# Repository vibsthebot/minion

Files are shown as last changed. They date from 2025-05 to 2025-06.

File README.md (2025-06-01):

# Minion - The Swiss Army Knife of Electronics

3D Model

I'm a mac user, and i love my apple wired headphones.
mN phone doesn't have headphone jack and my computer doesn't have micro sd or usb a.
What if i made a dongle to rule all dongles, but added a potentiometer for step tracking and display + buttons to play games? And thats how I made Minion.

## Features

- USB hub with usb c input, usb a and microsd output
- TRRS jack for headphones
- Bourns Rotary Encoder
- Built-in display (SSD1351)
- Tactile buttons for user input
- Robust case design with custom rotary encoder cover and button extensions

## [Onshape](https://cad.onshape.com/documents/3528835cd7c24f4fa682b200/w/cef528dd0bdfad9cc29e4192/e/ba726118fc6deb21c1d0aa06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)

## Images

### Schematic
Schematic

### PCB Layout
PCB

### 3D Model of PCB

3D Model

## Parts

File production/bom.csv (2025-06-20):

Designator | Footprint | Quantity | Value | LCSC Part #
BT1 | JST_PH_S2B-PH-K_1x02_P2.00mm_Horizontal | 1 | Battery | C265016
C1, C22, C27, C28 | 0805 | 4 | 4.7uF | C1779
C10, C11, C2, C23, C4, C5, C7 | 0805 | 7 | 10uF | C15850
C12, C13, C14, C15, C16, C17 | 0805 | 6 | 1uF | C28323
C18, C20, C21, C24, C26, C29, C3, C30, C31, C6, C8, C9 | 0805 | 12 | 0.1uF | C28233
C32, C33 | 0402 | 2 | 18pF | C1549
D1 | 0805 | 1 | PWRLED | C84256
D8 | 0805 | 1 | Orange | C434437
D9 | D_SOD-123 | 1 | MBR0540 | C77337
J1 | USB_C_Receptacle_HCTL_HC-TYPE-C-16P-01A | 1 | USB_C_Receptacle_USB2.0_16P | C134092
J2 | USB_A_Molex_67643_Horizontal | 1 | USB_A | C464564
J3 | CONN12_47309-2651_MOL | 1 | 473092651 | C587826
J4 | HRO_PJ-320D-A | 1 | PJ-320D-A | C95562
J5 | SSD_1351 | 1 | Conn_01x07_Socket | C124418
Q1 | SOT-23 | 1 | AO3401A | C306862
R1, R10, R2 | 0805 | 3 | 1k | C17513
R11 | 0805 | 1 | 2k | C17604
R12 | 0805 | 1 | 0.47k | C17710
R13, R14, R8, R9 | 0805 | 4 | 4k7 | C17673
R15, R16, R20, R5, R6, R7 | 0805 | 6 | 10k | C17414
R17, R18, R21 | 0805 | 3 | 100k | C149504
R19 | 0805 | 1 | 1M | C17514
R22 | 0805 | 1 | 12k | C17444
R3, R4 | 0805 | 2 | 5k1 | C27834
SW1, SW2, SW3 | SW_Push_1P1T_NO_6x6mm_H9.5mm | 3 | SW_Push | C455110
SW4 | RotaryEncoder_Bourns_Vertical_PEC12R-3x17F-Nxxxx | 1 | RotaryEncoder | C18164805
SW5, SW6 | SW_Push_1P1T_NO_CK_KMR2 | 2 | SW_Push | C221676
U1 | ESP32-S3-WROOM-1 | 1 | ESP32-S3-WROOM-1 | C2913204
U2, U3 | SOT-23-5 | 2 | AP2112K-3.3 | C51118
U4 | LGA-14_3x5mm_P0.8mm_LayoutBorder1x6y | 1 | ADXL343 | C579454
U6 | DFN-8-1EP_3x2mm_P0.5mm_EP1.7x1.4mm | 1 | MCP73831-2-MC | C150772
U7 | TSSOP-20_4.4x6.5mm_P0.65mm | 1 | PCM5102A | C1520792
U8 | QFN48_7X7MC_MCH | 1 | USB2641I-HZH-02 | C633597
Y3 | Crystal_SMD_5032-2Pin_5.0x3.2mm | 1 | 24MHz | C122520

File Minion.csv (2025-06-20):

Reference | Qty | Value | DigiKey | LCSC | DNP | Exclude from BOM | Exclude from Board | Footprint | Datasheet | MFR_NAME
BT1 | 1 | Battery |  | C265016 |  |  |  | Connector_JST:JST_PH_S2B-PH-K_1x02_P2.00mm_Horizontal | ~
C1,C19,C22 | 3 | 4.7uF |  | C40894 |  |  |  | Capacitor_SMD:C_0805_2012Metric | ~
C2,C12,C13,C14,C15,C16,C17 | 7 | 1uF |  | C215803 |  |  |  | Capacitor_SMD:C_0805_2012Metric | ~
C3,C6,C8,C9,C10,C18,C20,C21,C24 | 9 | 0.1uF |  | C476766 |  |  |  | Capacitor_SMD:C_0805_2012Metric | ~
C4,C5,C7,C11,C23 | 5 | 10uF |  | C40894 |  |  |  | Capacitor_SMD:C_0805_2012Metric | ~
D1 | 1 | PWRLED |  | C84256 |  |  |  | LED_SMD:LED_0805_2012Metric | ~
D2,D3,D4,D5 | 4 | WS2812B |  | C114586 |  |  |  | LED_SMD:LED_WS2812B_PLCC4_5.0x5.0mm_P3.2mm | https://cdn-shop.adafruit.com/datasheets/WS2812B.pdf
D6 | 1 | S-LMBR340FT1G |  | C2972823 |  |  |  | Diode_SMD:D_SOD-123F | ~
D8 | 1 | Orange |  | C434437 |  |  |  | LED_SMD:LED_0805_2012Metric | ~
D9 | 1 | MBR0540 |  | C77337 |  |  |  | Diode_SMD:D_SOD-123 | http://www.mccsemi.com/up_pdf/MBR0520~MBR0580(SOD123).pdf
DISPLAY_SSD1351 | 1 | Conn_01x07_Socket |  | C124418 |  |  |  | Connector_PinHeader_2.54mm:SSD_1351 | ~
H1,H2 | 2 | MountingHole |  |  |  | Excluded from BOM |  | MountingHole:MountingHole_2.2mm_M2 | ~
J1 | 1 | USB_C_Receptacle_USB2.0_16P | 900-2171790001CT-ND |  |  |  |  | Connector_USB:USB_C_Receptacle_HCTL_HC-TYPE-C-16P-01A | https://www.usb.org/sites/default/files/documents/usb_type-c.zip
J2 | 1 | USB_A |  | C464564 |  |  |  | Connector_USB:USB_A_Molex_67643_Horizontal | ~
J3 | 1 | 473092651 | WM6700CT-ND |  |  |  |  | 473092651:CONN12_47309-2651_MOL |  | Molex Connector Corporation
J4 | 1 | PJ-320D-A |  | C95562 |  |  |  | PJ-320D-A:HRO_PJ-320D-A
Q1 | 1 | AO3401A |  | C306862 |  |  |  | Package_TO_SOT_SMD:SOT-23 | http://www.aosmd.com/pdfs/datasheet/AO3401A.pdf
R1,R2,R10 | 3 | 1k |  | C95781 |  |  |  | Resistor_SMD:R_0805_2012Metric | ~
R3,R4 | 2 | 5.1k |  | C27834 |  |  |  | Resistor_SMD:R_0805_2012Metric | ~
R5,R6 | 2 | 10k |  | C2930231 |  |  |  | Resistor_SMD:R_0805_2012Metric | ~
R7 | 1 | 2.7k |  | C2907305 |  |  |  | Resistor_SMD:R_0805_2012Metric | ~
R8,R9,R13,R14 | 4 | 4.7k |  | C60816 |  |  |  | Resistor_SMD:R_0805_2012Metric | ~
R11 | 1 | 2k |  | C60816 |  |  |  | Resistor_SMD:R_0805_2012Metric | ~
R12 | 1 | 0.47k |  | C60816 |  |  |  | Resistor_SMD:R_0805_2012Metric | ~
SW1,SW2,SW3 | 3 | SW_Push |  | C455110 |  |  |  | Button_Switch_SMD:SW_Push_1P1T_NO_6x6mm_H9.5mm | ~
SW4 | 1 | RotaryEncoder |  | C18164805 |  |  |  | Rotary_Encoder:RotaryEncoder_Bourns_Vertical_PEC12R-3x17F-Nxxxx | ~
SW5,SW6 | 2 | SW_Push |  | C221676 |  |  |  | Button_Switch_SMD:SW_Push_1P1T_NO_CK_KMR2 | ~
U1 | 1 | ESP32-S3-WROOM-1 |  | C2913204 |  |  |  | RF_Module:ESP32-S3-WROOM-1 | https://www.espressif.com/sites/default/files/documentation/esp32-s3-wroom-1_wroom-1u_datasheet_en.pdf
U2 | 1 | AMS1117-3.3 | 4518-AMS1117-3.3CT-ND |  |  |  |  | Package_TO_SOT_SMD:SOT-223-3_TabPin2 | http://www.advanced-monolithic.com/pdf/ds1117.pdf
U3 | 1 | FE1.1s |  | C9359 |  |  |  | Package_SO:SSOP-28_3.9x9.9mm_P0.635mm | https://cdn-shop.adafruit.com/product-files/2991/FE1.1s+Data+Sheet+(Rev.+1.0).pdf
U4 | 1 | ADXL343 | 505-ADXL343BCCZ-ND |  |  |  |  | Package_LGA:LGA-14_3x5mm_P0.8mm_LayoutBorder1x6y | https://www.analog.com/media/en/technical-documentation/data-sheets/ADXL343.pdf
U5 | 1 | CH376T |  | C21282 |  |  |  | Package_SO:SSOP-20_5.3x7.2mm_P0.65mm | https://www.mpja.com/download/ch376ds1.pdf
U6 | 1 | MCP73831-2-MC |  | C150772 |  |  |  | Package_DFN_QFN:DFN-8-1EP_3x2mm_P0.5mm_EP1.7x1.4mm | http://ww1.microchip.com/downloads/en/DeviceDoc/20001984g.pdf
U7 | 1 | PCM5102A | 296-36707-1-ND |  |  |  |  | Package_SO:TSSOP-20_4.4x6.5mm_P0.65mm | https://www.ti.com/lit/ds/symlink/pcm5102a.pdf
Y1,Y2 | 2 | 12MHz |  | C3035202 |  |  |  | Crystal:Crystal_SMD_5032-2Pin_5.0x3.2mm | ~

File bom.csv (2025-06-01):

Qty | Item | LCSC/DigiKey Min Quantity | Individual Price | What the price should be | What the price really is | Price for 2 boards | LCSC Part Number | DigiKey Part Number | Link/Notes
1 | Battery | 10 | 0.0621 | 0.0621 | 0.621 | 0.62 | C265016
5 | 10uF | 50 | 0.012 | 0.06 | 0.6 | 0.6 | C40894
7 | 1uF | 25 | 0.0034 | 0.0238 | 0.085 | 0.09 | C215803
5 | 0.1uF | 20 | 0.0097 | 0.0485 | 0.194 | 0.19 | C476766
1 | PWRLED | 50 | 0.013 | 0.013 | 0.65 | 0.65 | C84256
4 | WS2812B | 5 | 0.0835 | 0.334 | 0.4175 | 0.84 | C114586
1 | S-LMBR340FT1G | 10 | 0.0249 | 0.0249 | 0.249 | 0.25 | C2972823
1 | Orange | 50 | 0.0088 | 0.0088 | 0.44 | 0.44 | C434437
1 | MBR0540 | 20 | 0.0313 | 0.0313 | 0.626 | 0.63 | C77337
1 | Conn_01x07_Socket | 5 | 0.1469 | 0.1469 | 0.7345 | 0.73 | C124418
1 | USB_C_Receptacle_USB2.0_16P | 1 | 0.83 | 0.83 | 0.83 | 1.66 |  | 900-2171790001CT-ND
1 | USB_A | 1 | 0.5764 | 0.5764 | 0.5764 | 1.15
1 | 473092651 | 1 | 1.94 | 1.94 | 1.94 | 3.88 | C464564 | WM6700CT-ND
1 | PJ-320D-A | 5 | 0.0972 | 0.0972 | 0.486 | 0.49
1 | AO3401A | 20 | 0.0521 | 0.0521 | 1.042 | 1.04 | C95562
3 | 1k | 100 | 0.0019 | 0.0057 | 0.19 | 0.19 | C306862
2 | 5.1k | 100 | 0.0019 | 0.0038 | 0.19 | 0.19 | C95781
2 | 10k | 100 | 0.0012 | 0.0024 | 0.12 | 0.12 | C27834
1 | 2.7k | 100 | 0.0013 | 0.0013 | 0.13 | 0.13 | C2930231
6 | 4.7k | 100 | 0.0022 | 0.0132 | 0.22 | 0.22 | C2907305
3 | SW_Push | 10 | 0.0427 | 0.1281 | 0.427 | 0.43 | C60816
1 | RotaryEncoder | 1 | 2.3596 | 2.3596 | 2.3596 | 4.72 | C455110
2 | SW_Push | 1 | 0.4706 | 0.9412 | 0.9412 | 1.88 | C18164805
1 | ESP32-S3-WROOM-1 | 1 | 5.8792 | 5.8792 | 5.8792 | 11.76 | C221676
1 | AMS1117-3.3 | 1 | 0.68 | 0.68 | 0.68 | 1.36 | C2913204 | 4518-AMS1117-3.3CT-ND
1 | FE1.1s | 1 | 0.6214 | 0.6214 | 0.6214 | 1.24
1 | ADXL343 | 1 | 3.35 | 3.35 | 3.35 | 6.7 | C9359 | 505-ADXL343BCCZ-ND
1 | CH376T | 1 | 3.6696 | 3.6696 | 3.6696 | 7.34
1 | MCP73831-2-MC | 1 | 1.2194 | 1.2194 | 1.2194 | 2.44 | C21282
1 | PCM5102A | 1 | 4.43 | 4.43 | 4.43 | 8.86 | C150772 | 296-36707-1-ND
2 | 12MHz | 5 | 0.1676 | 0.3352 | 0.838 | 0.84
1 | SSD1351 | 1 | 19.55 | 19.55 | 19.55 | 19.55 | C3035202
1 | Stencils + PCB | 1 | 16 | 16 | 16 | 16 |  |  | https://www.aliexpress.us/item/2255799949791867.html
1 | JLCCNC Machined case | 1 | 61.87 | 61.87 | 61.87 | 61.87 |  |  | optional, may get manufactured in house
1 | DigiKey Shipping | 1 | 8 | 8 | 8 | 8
1 | LCSC + JLC shipping | 1 | 20 | 20 | 20 | 20
 |  |  | 152.2099 | 153.3091 | 160.1768 | 187.1

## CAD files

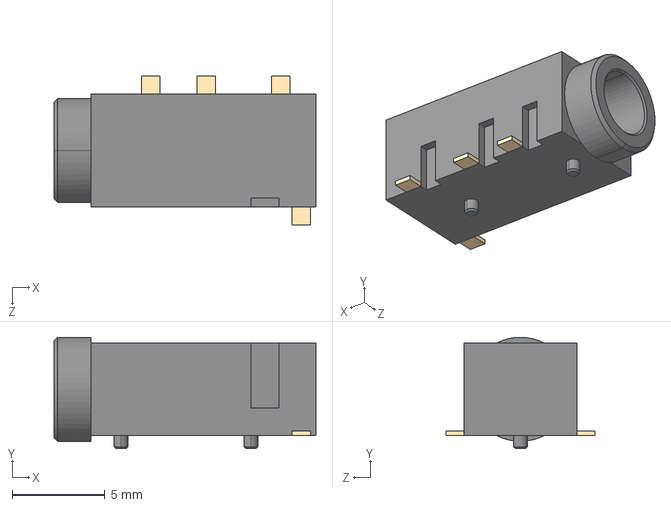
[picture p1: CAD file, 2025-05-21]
3d models/PJ-320D-A--3DModel-STEP-56544.STEP
14.1 x 6.00 x 8.00 mm

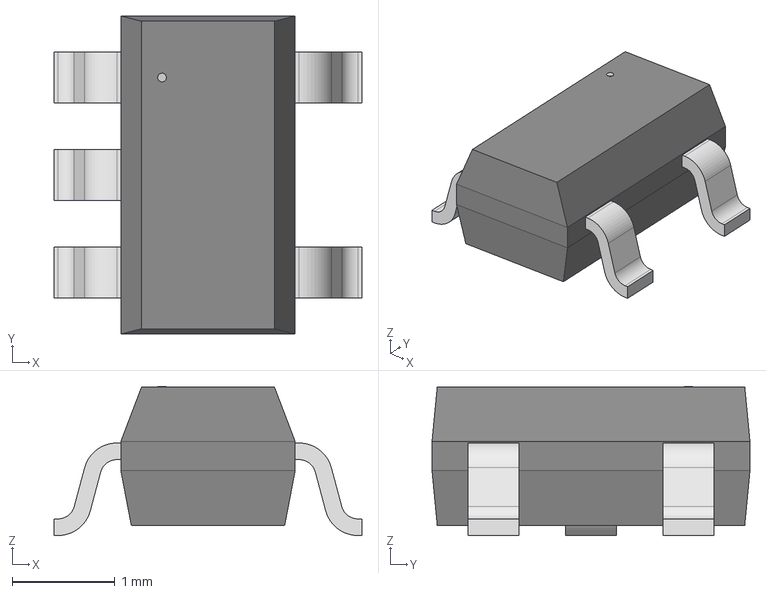
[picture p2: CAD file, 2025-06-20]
74AHCT1G125W5_7/SOT25_DIO.step
3.00 x 3.10 x 1.45 mm

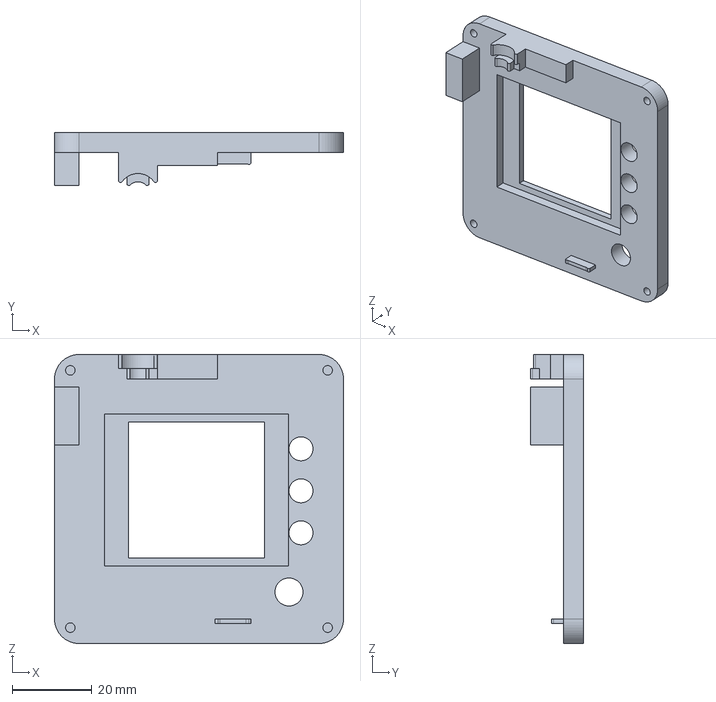
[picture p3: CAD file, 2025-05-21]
CAD/top_shell.step
72.3 x 13.3 x 72.3 mm

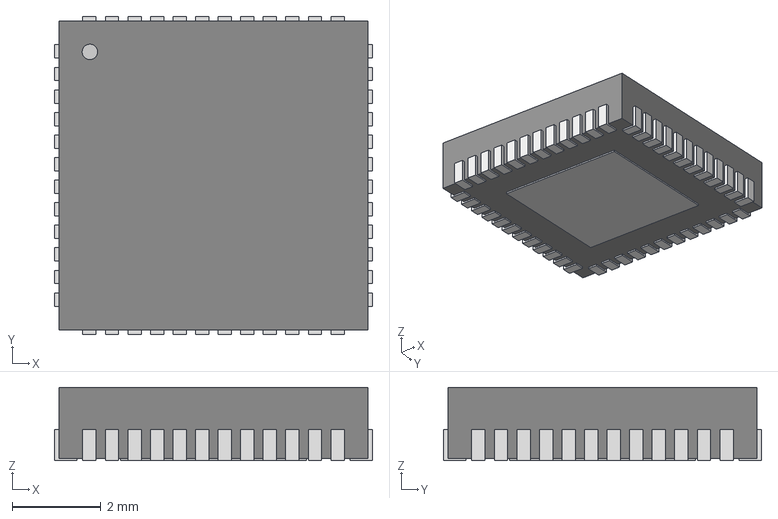
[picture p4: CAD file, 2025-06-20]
USB2641I_HZH_02/QFN48_7X7MC_MCH.step
7.16 x 7.16 x 1.65 mm

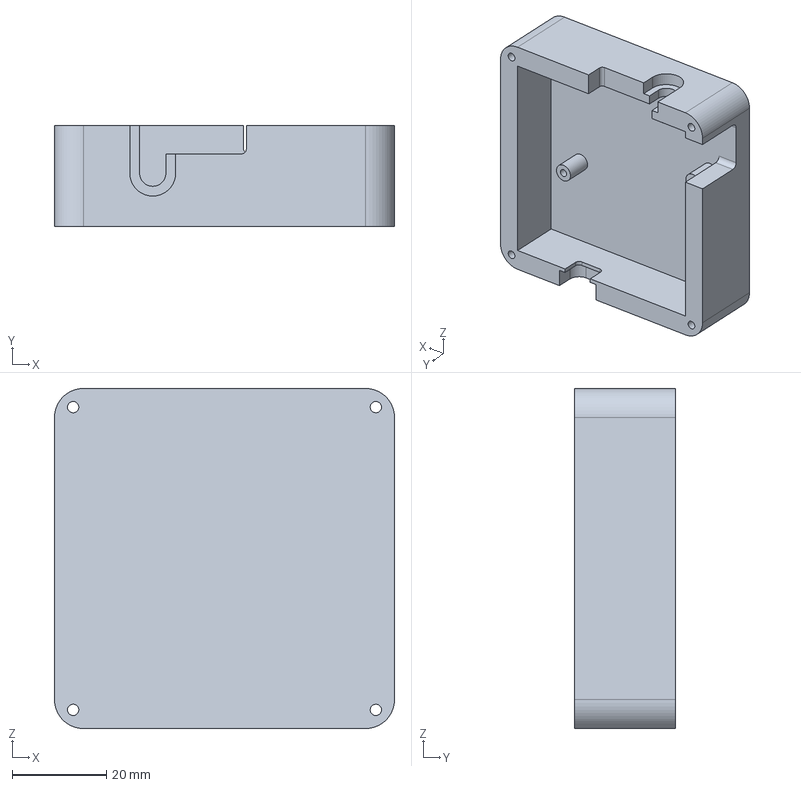
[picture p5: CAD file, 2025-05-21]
CAD/bottom_shell.step
72.3 x 21.5 x 72.3 mm

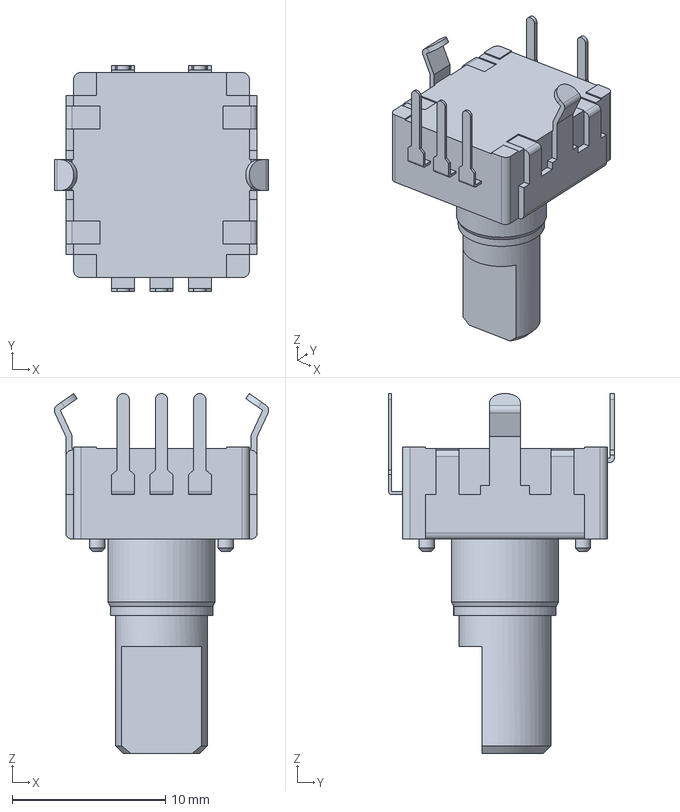
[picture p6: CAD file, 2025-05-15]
3d models/pec12r-4020f-n0024.step
14.0 x 14.7 x 23.5 mm

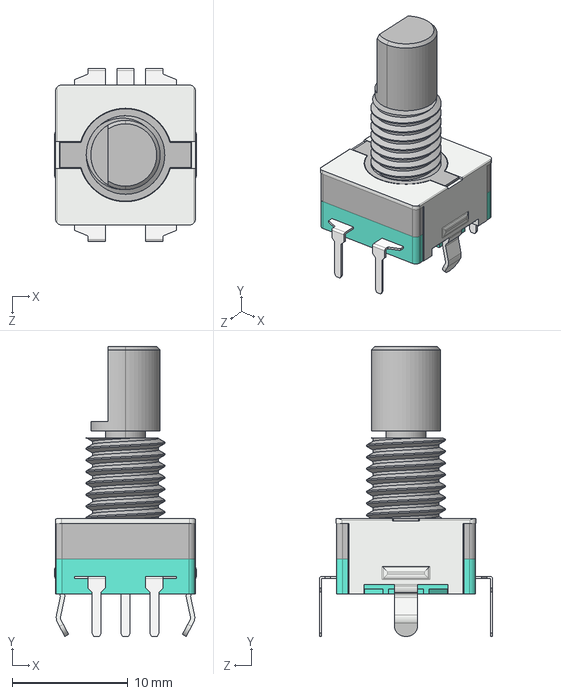
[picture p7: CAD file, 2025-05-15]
3d models/ec11.STEP
12.3 x 25.1 x 15.0 mm

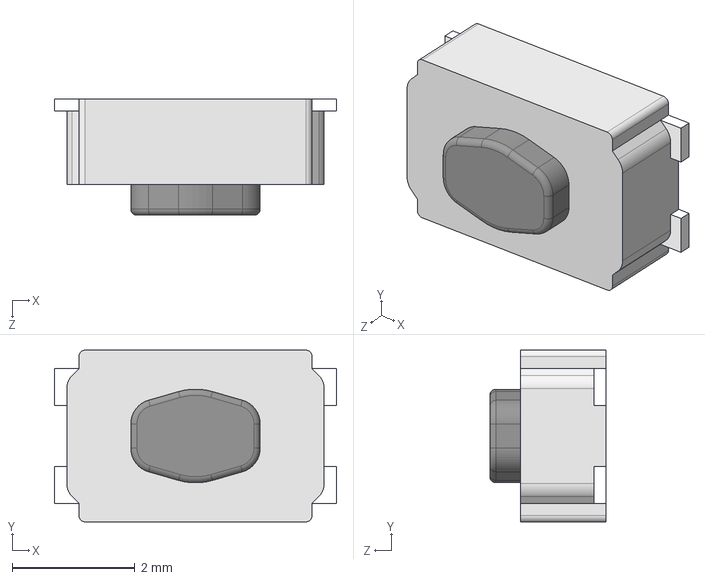
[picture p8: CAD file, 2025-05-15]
3d models/CK-KMR-2.STEP
4.60 x 2.80 x 1.90 mm

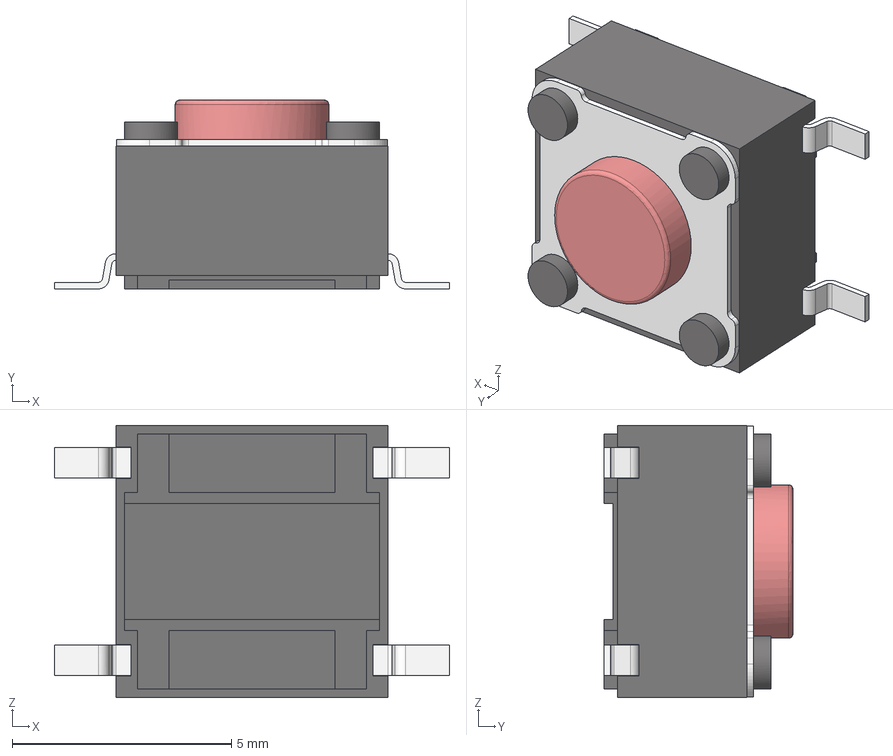
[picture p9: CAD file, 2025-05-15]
3d models/Tact Switch SMD 6x6mm.step
9.00 x 4.30 x 6.20 mm

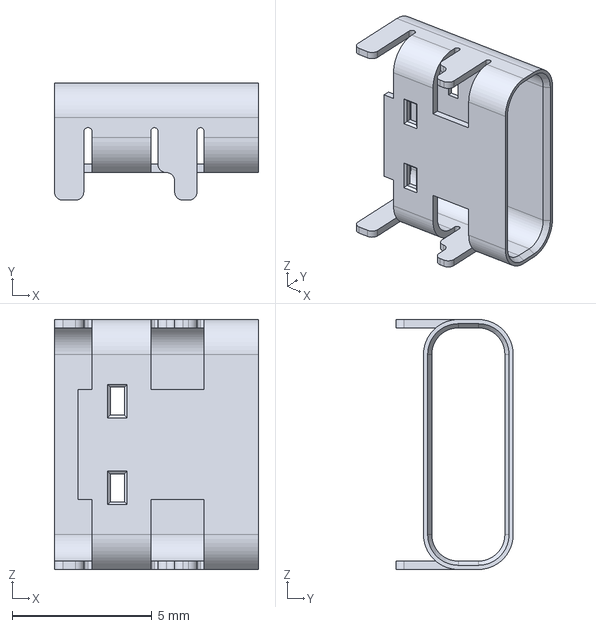
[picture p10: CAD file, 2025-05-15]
3d models/usb-c horizontal surface mount - usbc.step
7.30 x 4.20 x 8.94 mm

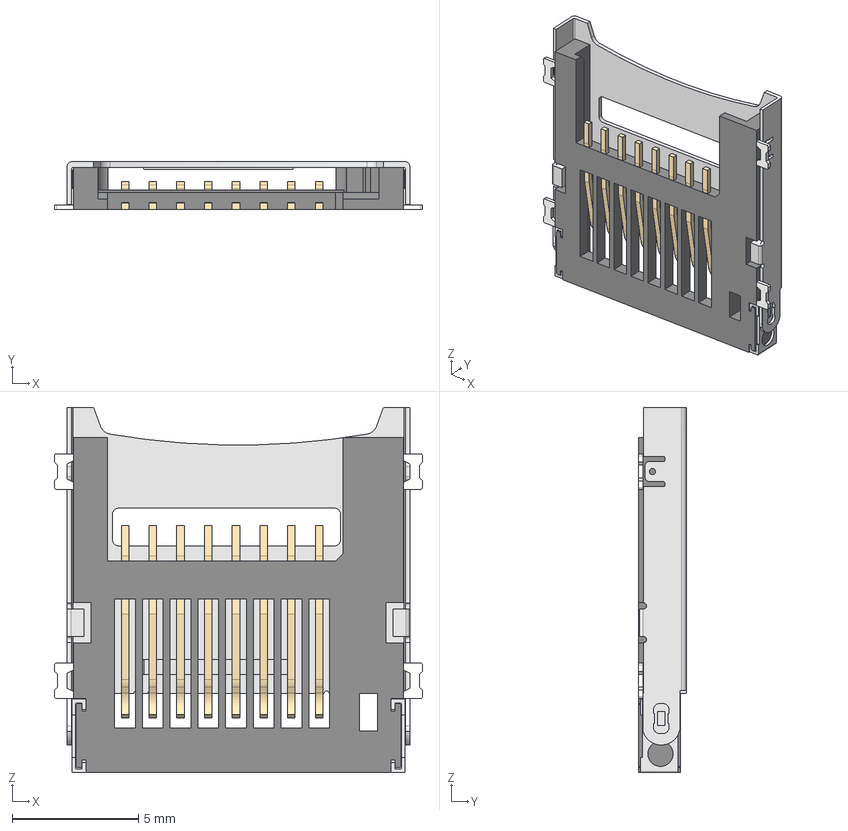
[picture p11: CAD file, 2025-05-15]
3d models/molex-47219-2001-1.snapshot.1/472192001 v1.step
14.6 x 1.90 x 14.5 mm
Pins
Mounting
Cover
Hinge

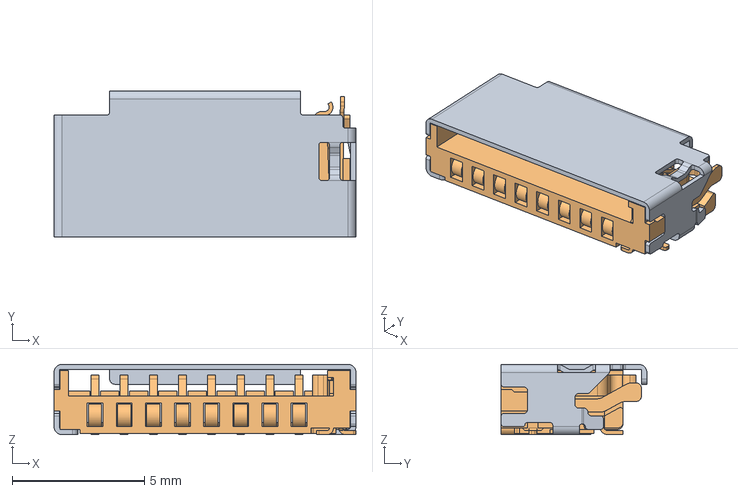
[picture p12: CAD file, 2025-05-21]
3d models/473092651.stp
11.4 x 5.50 x 2.65 mm

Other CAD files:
3d models/molex-47219-2001-1.snapshot.1/472192001 v1.f3d

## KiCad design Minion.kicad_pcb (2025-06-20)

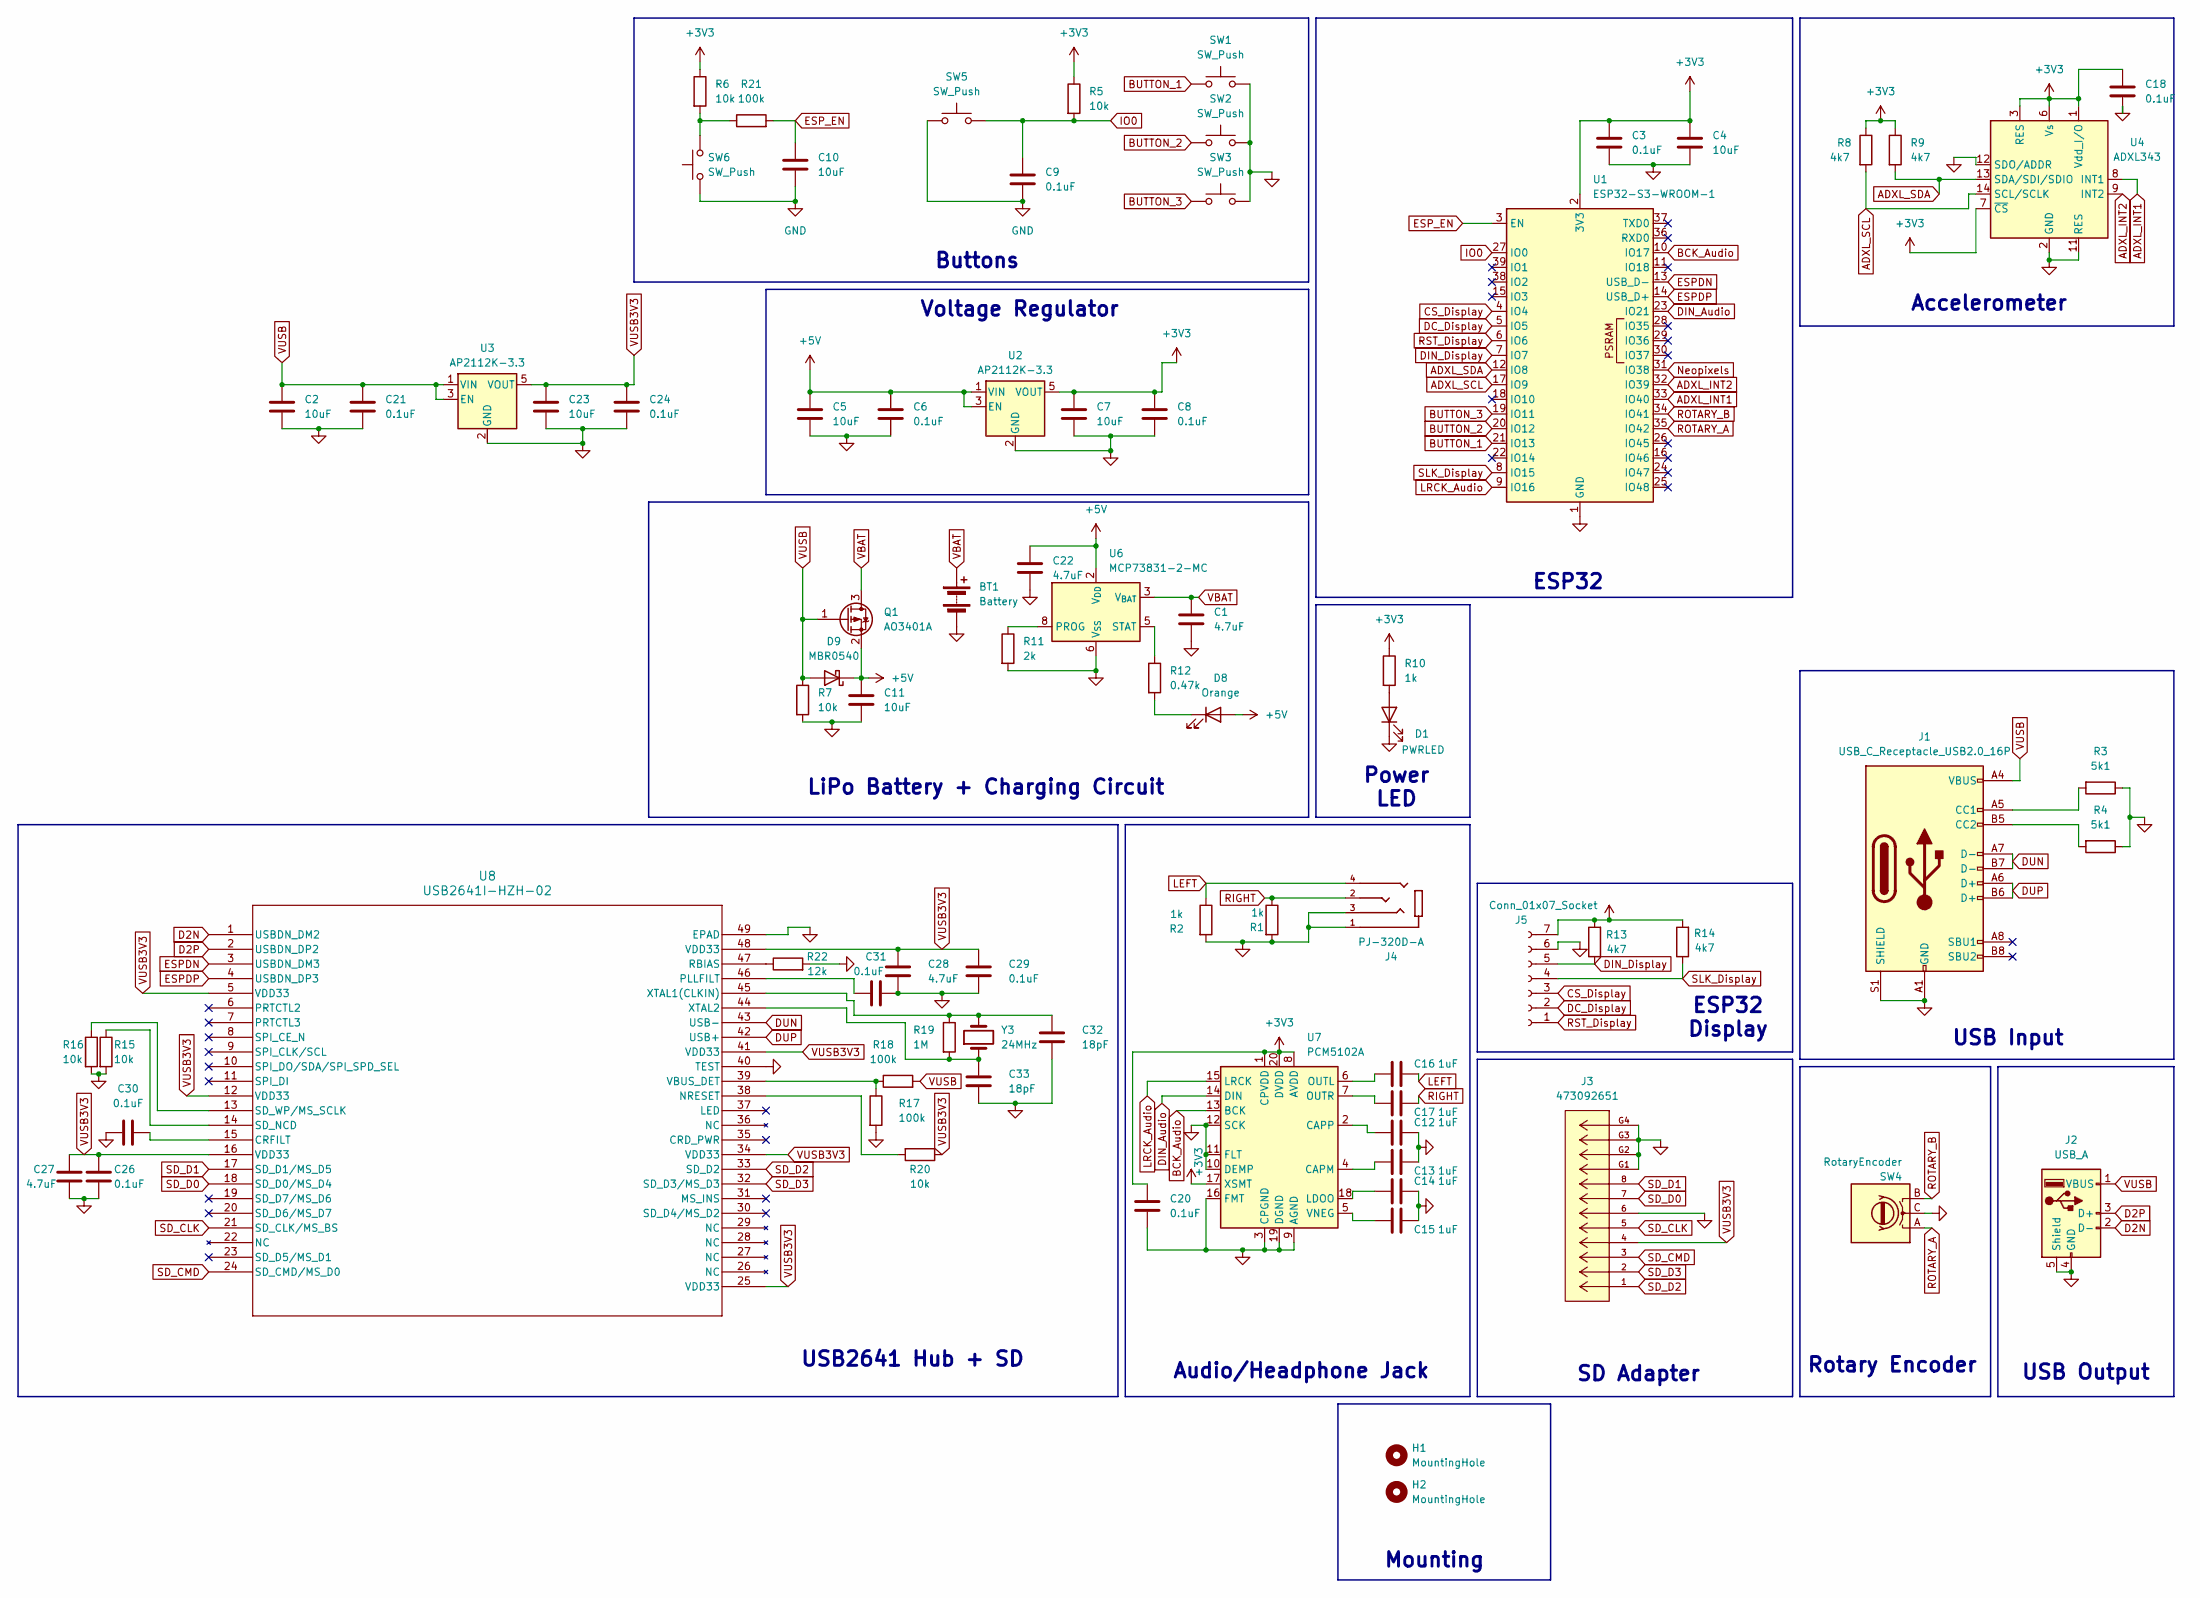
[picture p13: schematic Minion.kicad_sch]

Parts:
BT1: Battery; JST_PH_S2B-PH-K_1x02_P2.00mm_Horizontal; LCSC C265016
C1, C22, C27, C28: 4.7uF; C_0805_2012Metric; LCSC C1779
C2, C4, C5, C7, C10, C11, C23: 10uF; C_0805_2012Metric; LCSC C15850
C3, C6, C8, C9, C18, C20, C21, C24, C26, C29, C30, C31: 0.1uF; C_0805_2012Metric; LCSC C28233
C12, C13, C14, C15, C16, C17: 1uF; C_0805_2012Metric; LCSC C28323
C32, C33: 18pF; C_0402_1005Metric; LCSC C1549
D1: PWRLED; LED_0805_2012Metric; LCSC C84256
D8: Orange; LED_0805_2012Metric; LCSC C434437
D9: MBR0540; D_SOD-123; LCSC C77337
H1, H2: MountingHole; MountingHole_2.2mm_M2
J1: USB_C_Receptacle_USB2.0_16P; USB_C_Receptacle_HCTL_HC-TYPE-C-16P-01A; DigiKey 900-2171790001CT-ND
J2: USB_A; USB_A_Molex_67643_Horizontal; LCSC C464564
J3: 473092651; CONN12_47309-2651_MOL; MANUFACTURER_PART_NUMBER 473092651; DigiKey WM6700CT-ND
J4: PJ-320D-A; HRO_PJ-320D-A; PARTREV B; LCSC C95562
J5: Conn_01x07_Socket; SSD_1351; LCSC C124418
Q1: AO3401A; SOT-23; LCSC C306862
R1, R2, R10: 1k; R_0805_2012Metric; LCSC C17513
R3, R4: 5k1; R_0805_2012Metric; LCSC C27834
R5, R6, R7, R15, R16, R20: 10k; R_0805_2012Metric; LCSC C17414
R8, R9, R13, R14: 4k7; R_0805_2012Metric; LCSC C17673
R11: 2k; R_0805_2012Metric; LCSC C17604
R12: 0.47k; R_0805_2012Metric; LCSC C17710
R17, R18, R21: 100k; R_0805_2012Metric; LCSC C149504
R19: 1M; R_0805_2012Metric; LCSC C17514
R22: 12k; R_0805_2012Metric; LCSC C17444
SW1, SW2, SW3: SW_Push; SW_Push_1P1T_NO_6x6mm_H9.5mm; LCSC C455110
SW4: RotaryEncoder; RotaryEncoder_Bourns_Vertical_PEC12R-3x17F-Nxxxx; LCSC C18164805
SW5, SW6: SW_Push; SW_Push_1P1T_NO_CK_KMR2; LCSC C221676
U1: ESP32-S3-WROOM-1; LCSC C2913204
U2, U3: AP2112K-3.3; SOT-23-5; LCSC C51118
U4: ADXL343; LGA-14_3x5mm_P0.8mm_LayoutBorder1x6y; DigiKey 505-ADXL343BCCZ-ND
U6: MCP73831-2-MC; DFN-8-1EP_3x2mm_P0.5mm_EP1.7x1.4mm; LCSC C150772
U7: PCM5102A; TSSOP-20_4.4x6.5mm_P0.65mm; DigiKey 296-36707-1-ND
U8: USB2641I-HZH-02; QFN48_7X7MC_MCH; LCSC C633597
Y3: 24MHz; Crystal_SMD_5032-2Pin_5.0x3.2mm; LCSC C122520

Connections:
+3V3: C3.1, C4.1, C7.1, C8.1, C18.1, C20.1, J5.7, R5.1, R6.1, R8.1, R9.1, R10.1, R13.2, R14.2, U1.2 (3V3), U2.5 (VOUT), U4.1 (Vdd_I/O), U4.3 (RES), U4.6 (Vs), U4.7 (~CS), U7.1 (CPVDD), U7.8 (AVDD), U7.17 (XSMT), U7.20 (DVDD)
+5V: C5.1, C6.1, C11.1, C22.1, D8.2 (A), D9.1 (K), Q1.2 (S), U2.1 (VIN), U2.3 (EN), U6.1 (V_{DD}), U6.2 (V_{DD})
ADXL_INT1: U1.33 (IO40), U4.8 (INT1)
ADXL_INT2: U1.32 (IO39), U4.9 (INT2)
ADXL_SCL: R8.2, U1.17 (IO9), U4.14 (SCL/SCLK)
ADXL_SDA: R9.2, U1.12 (IO8), U4.13 (SDA/SDI/SDIO)
BCK_Audio: U1.10 (IO17), U7.13 (BCK)
BUTTON_1: SW1.1, U1.21 (IO13)
BUTTON_2: SW2.1, U1.20 (IO12)
BUTTON_3: SW3.1, U1.19 (IO11)
CS_Display: J5.3, U1.4 (IO4)
D2N: J2.2 (D-), U8.1 (USBDN_DM2)
D2P: J2.3 (D+), U8.2 (USBDN_DP2)
DC_Display: J5.2, U1.5 (IO5)
DIN_Audio: U1.23 (IO21), U7.14 (DIN)
DIN_Display: J5.5, R13.1, U1.7 (IO7)
DUN: J1.A7 (D-), J1.B7 (D-), U8.43 (USB-)
DUP: J1.A6 (D+), J1.B6 (D+), U8.42 (USB+)
ESPDN: U1.13 (USB_D-), U8.3 (USBDN_DM3)
ESPDP: U1.14 (USB_D+), U8.4 (USBDN_DP3)
ESP_EN: C10.1, R21.2, U1.3 (EN)
GND: BT1.2 (-), C1.2, C2.2, C3.2, C4.2, C5.2, C6.2, C7.2, C8.2, C9.2, C10.2, C11.2, C12.2, C13.2, C14.2, C15.2, C18.2, C20.2, C21.2, C22.2, C23.2, C24.2, C26.2, C27.2, C28.2, C29.2, C30.1, C31.2, C32.2, C33.2, D1.1 (K), J1.A1 (GND), J1.A12 (GND), J1.B1 (GND), J1.B12 (GND), J1.S1 (SHIELD), J2.4 (GND), J2.5 (Shield), J3.6, J3.G1, J3.G2, J3.G3, J3.G4, J4.1, J4.3, J5.6, R1.2, R2.2, R3.1, R4.1, R7.2, R11.2, R15.2, R16.2, R17.2, R22.2, SW1.2, SW2.2, SW3.2, SW4.C, SW5.1, SW6.1, U1.1 (GND), U1.40 (GND), U1.41 (GND), U2.2 (GND), U3.2 (GND), U4.2 (GND), U4.4 (GND), U4.5 (GND), U4.11 (RES), U4.12 (SDO/ADDR), U6.6 (V_{SS}), U7.3 (CPGND), U7.9 (AGND), U7.10 (DEMP), U7.11 (FLT), U7.12 (SCK), U7.16 (FMT), U7.19 (DGND), U8.40 (TEST), U8.49 (EPAD)
IO0: C9.1, R5.2, SW5.2, U1.27 (IO0)
LEFT: C16.2, J4.4, R2.1
LRCK_Audio: U1.9 (IO16), U7.15 (LRCK)
Neopixels: U1.31 (IO38)
unnamed: D1.2 (A), R10.2
unnamed: D8.1 (K), R12.2
unnamed: J1.A5 (CC1), R3.2
unnamed: J1.B5 (CC2), R4.2
unnamed: R6.2, R21.1, SW6.2
unnamed: R11.1, U6.8 (PROG)
unnamed: R12.1, U6.5 (STAT)
unnamed: C13.1, U7.4 (CAPM)
unnamed: C12.1, U7.2 (CAPP)
unnamed: C14.1, U7.18 (LDOO)
unnamed: C16.1, U7.6 (OUTL)
unnamed: C17.1, U7.7 (OUTR)
unnamed: C15.1, U7.5 (VNEG)
unnamed: C30.2, U8.15 (CRFILT)
unnamed: R20.2, U8.38 (NRESET)
unnamed: C31.1, U8.46 (PLLFILT)
unnamed: R22.1, U8.47 (RBIAS)
unnamed: R15.1, U8.14 (SD_NCD)
unnamed: R16.1, U8.13 (SD_WP/MS_SCLK)
unnamed: R17.1, R18.1, U8.39 (VBUS_DET)
unnamed: C32.1, R19.1, U8.45 (XTAL1(CLKIN)), Y3.2
unnamed: C33.1, R19.2, U8.44 (XTAL2), Y3.1
RIGHT: C17.2, J4.2, R1.1
ROTARY_A: SW4.A, U1.35 (IO42)
ROTARY_B: SW4.B, U1.34 (IO41)
RST_Display: J5.1, U1.6 (IO6)
SD_CLK: J3.5, U8.21 (SD_CLK/MS_BS)
SD_CMD: J3.3, U8.24 (SD_CMD/MS_D0)
SD_D0: J3.7, U8.18 (SD_D0/MS_D4)
SD_D1: J3.8, U8.17 (SD_D1/MS_D5)
SD_D2: J3.1, U8.33 (SD_D2)
SD_D3: J3.2, U8.32 (SD_D3/MS_D3)
SLK_Display: J5.4, R14.1, U1.8 (IO15)
VBAT: BT1.1 (+), C1.1, Q1.3 (D), U6.3 (V_{BAT}), U6.4 (V_{BAT})
VUSB: C2.1, C21.1, D9.2 (A), J1.A4 (VBUS), J1.A9 (VBUS), J1.B4 (VBUS), J1.B9 (VBUS), J2.1 (VBUS), Q1.1 (G), R7.1, R18.2, U3.1 (VIN), U3.3 (EN)
VUSB3V3: C23.1, C24.1, C26.1, C27.1, C28.1, C29.1, J3.4, R20.1, U3.5 (VOUT), U8.5 (VDD33), U8.12 (VDD33), U8.16 (VDD33), U8.25 (VDD33), U8.34 (VDD33), U8.41 (VDD33), U8.48 (VDD33)

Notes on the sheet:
Voltage Regulator
Buttons
Audio/Headphone Jack
ESP32
Power LED
Mounting
USB2641 Hub + SD
Accelerometer
LiPo Battery + Charging Circuit
USB Input
USB Output
Rotary Encoder
SD Adapter
ESP32 Display

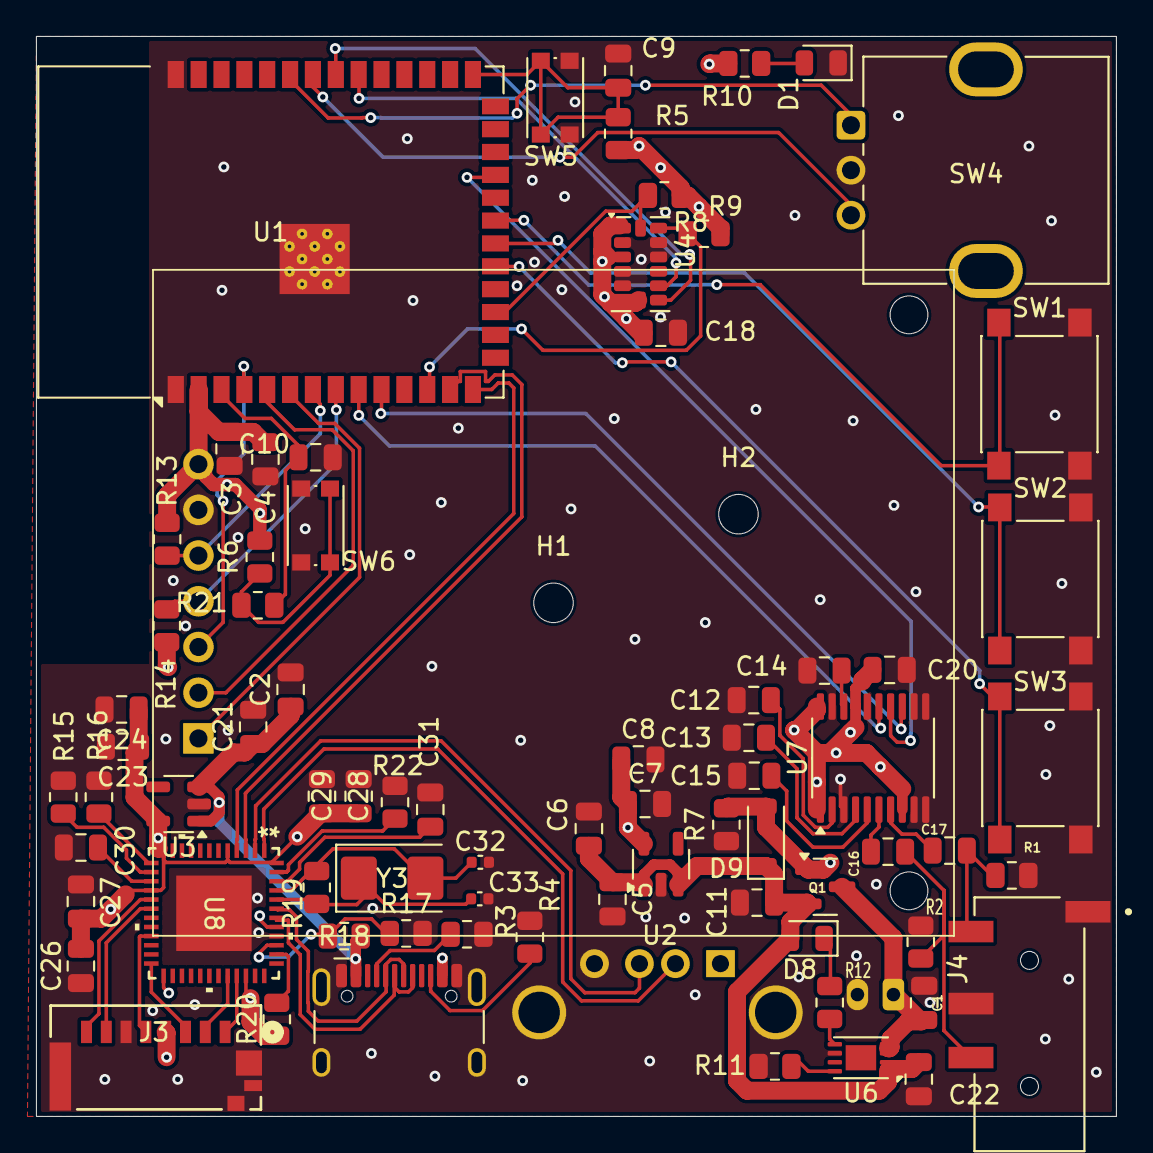
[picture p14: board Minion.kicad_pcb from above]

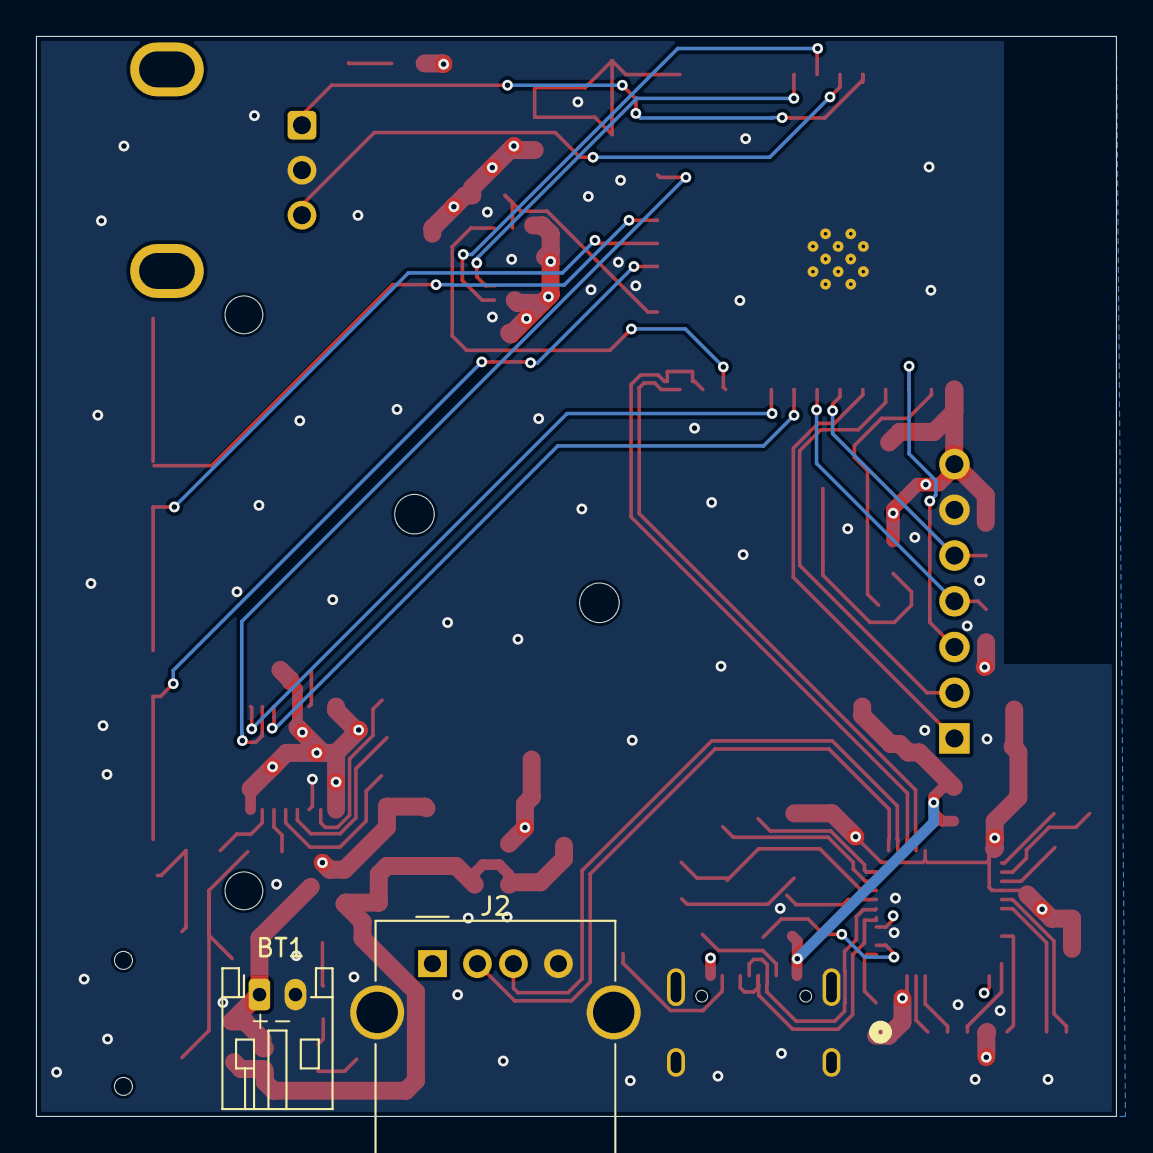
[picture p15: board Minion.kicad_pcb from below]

Board: 4 copper layers, 60.0 x 60.0 mm, 79 parts (2 on the bottom side), 61 nets.

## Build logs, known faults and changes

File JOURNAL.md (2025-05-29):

## Total time: 24.5 hours

## May 20
Added LCSC/Digikey part numbers for all parts in the PCB


### Time Spent: 3 hours

## May 19
Finished CAD for case, rotary encoder cover, and button extensions. 


### Time Spent: 3 hours

## May 18 evening
Redid all the routing and moved some placements to add the TRRS jack and fix capacitators.


### Time Spent: 2 hours

## May 18 morning
I worked on implementing the TRRS jack in the schematic, which I completly forgot to do at the beginning.


### Time Spent: 1.5 hours

## May 16
I worked on finishing the PCB! I switched the vertical usb to a horizontal one and put it on the back, and I also fixed silkscreen warnings.


### Time Spent: 2 hours

## May 15
I worked on finding 3d models for all the different parts in the PCB! I haven't found a model for the vertical usb but I might change it.



### Time spent: 3 hours

## May 14
Finished routing + added ground fill
<video src="https://hc-cdn.hel1.your-objectstorage.com/s/v3/c80ffae81c3330d9f34ce0425b0769a1eda110e2_screen_recording_2025-05-14_at_2.15.43___pm.mp4" controls></video>

### Time Spent: 1 hours

## May 13
Worked on adding footprints for my components, and also started routing!
<video src="https://hc-cdn.hel1.your-objectstorage.com/s/v3/ee8c2af58853564d9ff8c342c9df8804f398fe2f_screen_recording_2025-05-13_at_6.33.43___pm.mp4" controls></video>

### Time Spent: 3 hours

## May 12
Finished schematic today, added lipo charging circuit and esp32 screen circuit with ssd1351 ($35.00 :skull:)
<video src="https://cdn.hack.ngo/slackcdn/fa5fc0be8631bb76218d4fe1aa26c552.mov" controls></video>

### Time Spent: 2 hours

## May 10
Added accelerometer, cleaned up schematic so everything is neater, finished fe1.1s schematic, added usb to sd card schematic
<video src="https://cdn.hack.ngo/slackcdn/8400c554028582b877293d270e8196d5.mov" controls></video>

### Time Spent: 2 hours

## May 9
Added usb splitter, reset button, still need to add sd card
<video src="https://cdn.hack.ngo/slackcdn/8400c554028582b877293d270e8196d5.mov" controls></video>

### Time Spent: 1 hours

## May 8
Worked on getting buttons, esp32 finished, and rotary encoder, trying to figure out how to add trrs jack
<video src="https://cdn.hack.pet/slackcdn/fb65dc88012bf200833ebe5790fde993.mov" controls></video>

### Time Spent: 1 hours

## May 5
Worked on getting basic ESP32 schematic up, took some time as it is my first advanced PCB
<video src="https://hc-cdn.hel1.your-objectstorage.com/s/v3/5d7c1b3730a864895606c913d410d1b6f17ded59_screen_recording_2025-05-05_at_10.57.29___am.mp4" controls></video>

### Time Spent: 1 hours

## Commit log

2025-05-02 created project
    [Minion.kicad_pcb, Minion.kicad_sch]
2025-05-15 finished most of pcb, added 3d models
    [472192001 v1.f3d, 472192001 v1.step, CK-KMR-2.STEP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]
2025-05-21 finished pcb and updated journal
    [473092651.stp, Minion.csv, Minion.kicad_pcb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]
2025-05-29 updated journal and readme
    [Minion.csv, Minion.kicad_sch, bom.csv]
2025-06-01 added bom with prices
    [Minion.csv, Minion.kicad_sch, bom.csv]
2025-06-01 fixed bom with shipping
    [bom.csv]
2025-06-12 Updated from feedback
    [Minion.kicad_pcb, Minion.kicad_sch, bom.csv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]
2025-06-20 Finished PCB!
    [Minion.csv, Minion.kicad_pcb, Minion.kicad_sch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]
